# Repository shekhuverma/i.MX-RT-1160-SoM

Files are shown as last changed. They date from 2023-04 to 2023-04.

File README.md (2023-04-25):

You can read the full blog post [here](https://shekharverma.com/posts/imxrt_som/)!

**The SoM Features**
* i.MX RT 1160 MCU (MIMXRT1166DVM6A)
* 128 Mb SD RAM
* 128 Mb QSPI Flash
* 4 Gb eMMC
* 10/100 Mbps RMII Ethernet PHY
* 2 Lane MIPI-DSI
* 2 Lane MIPI-CSI
* 2 X USB 2.0
* 2 X I2C
* UART to USB Convertor
* Multiple GPIOs
* 2 X 48 Pin Board-to-Board Connector

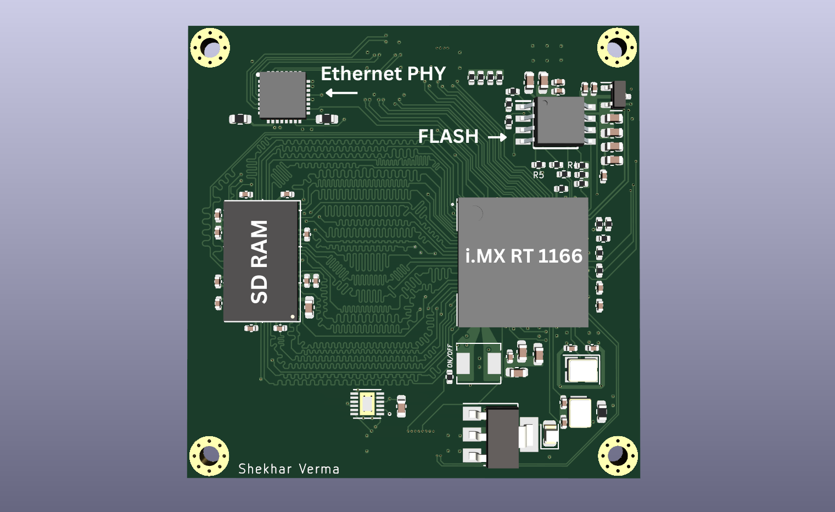
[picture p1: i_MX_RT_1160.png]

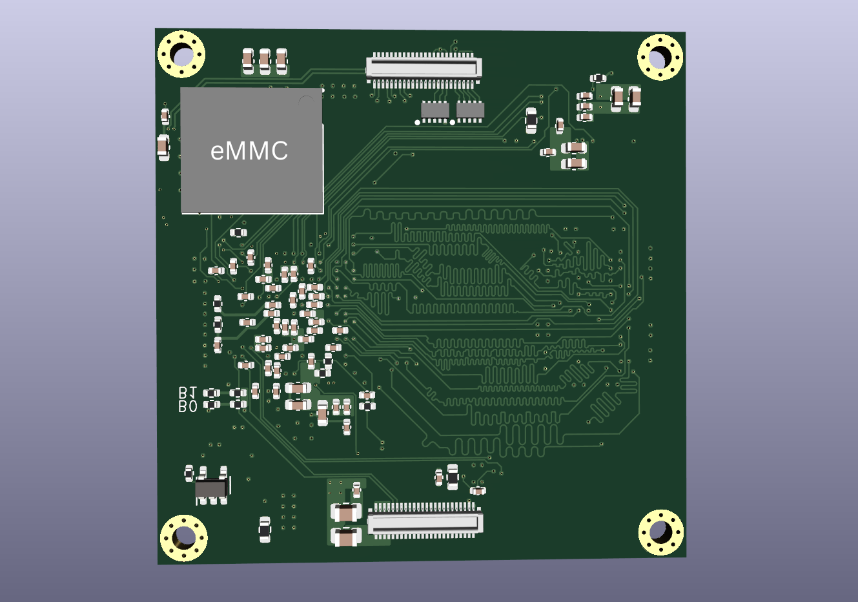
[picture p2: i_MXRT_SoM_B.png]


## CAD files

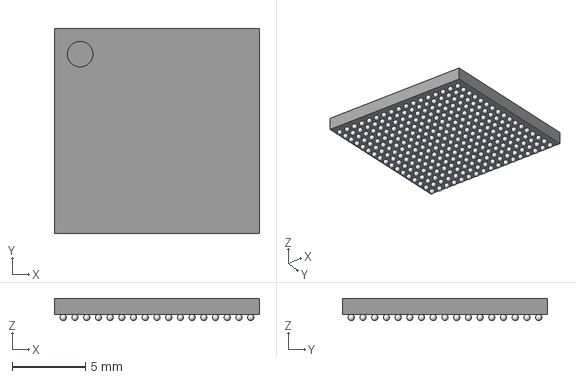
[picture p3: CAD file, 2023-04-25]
Components/MIMXRT1166DVM6A/MIMXRT1166DVM6A.stp
14.0 x 14.0 x 1.52 mm

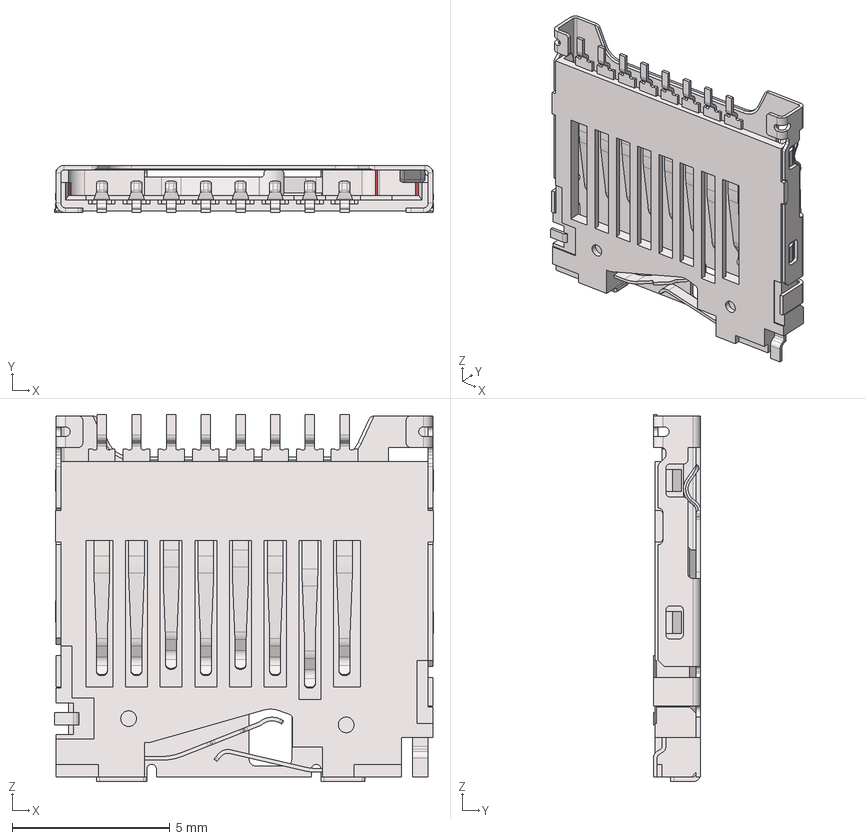
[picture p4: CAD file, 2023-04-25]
Components/1140084168/1140084168.step
12.0 x 1.50 x 11.7 mm

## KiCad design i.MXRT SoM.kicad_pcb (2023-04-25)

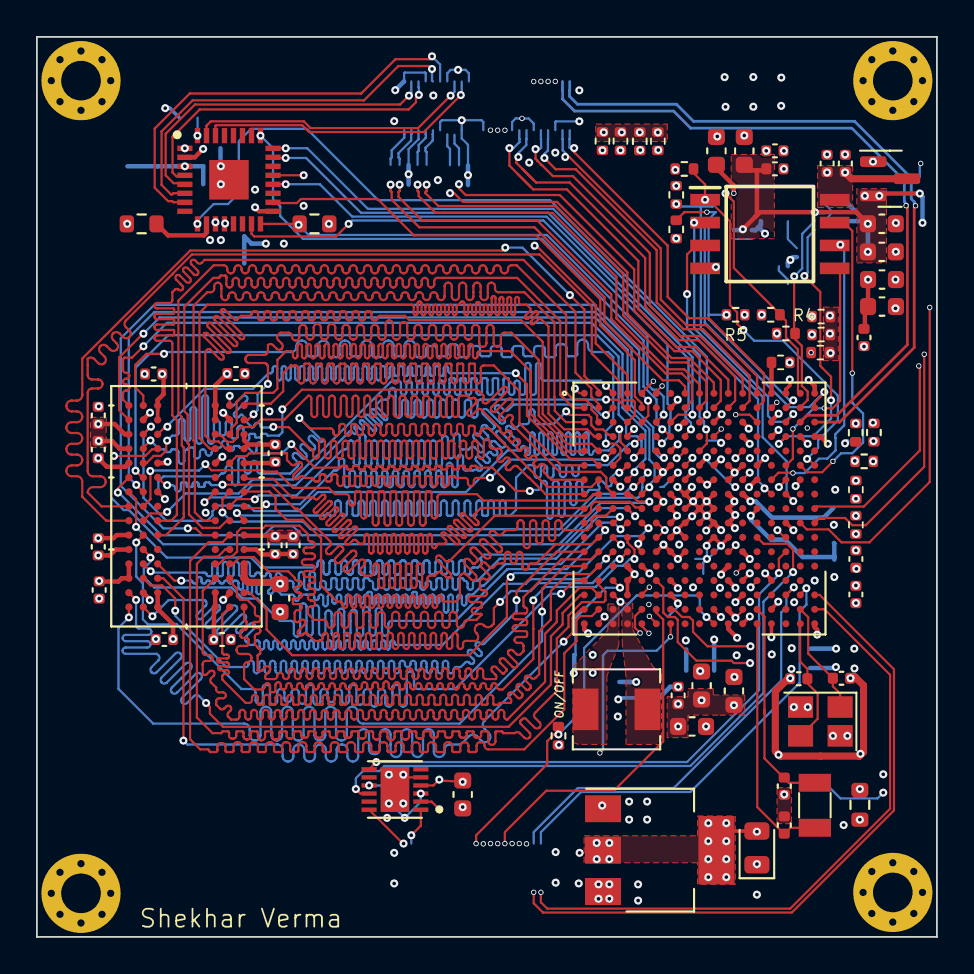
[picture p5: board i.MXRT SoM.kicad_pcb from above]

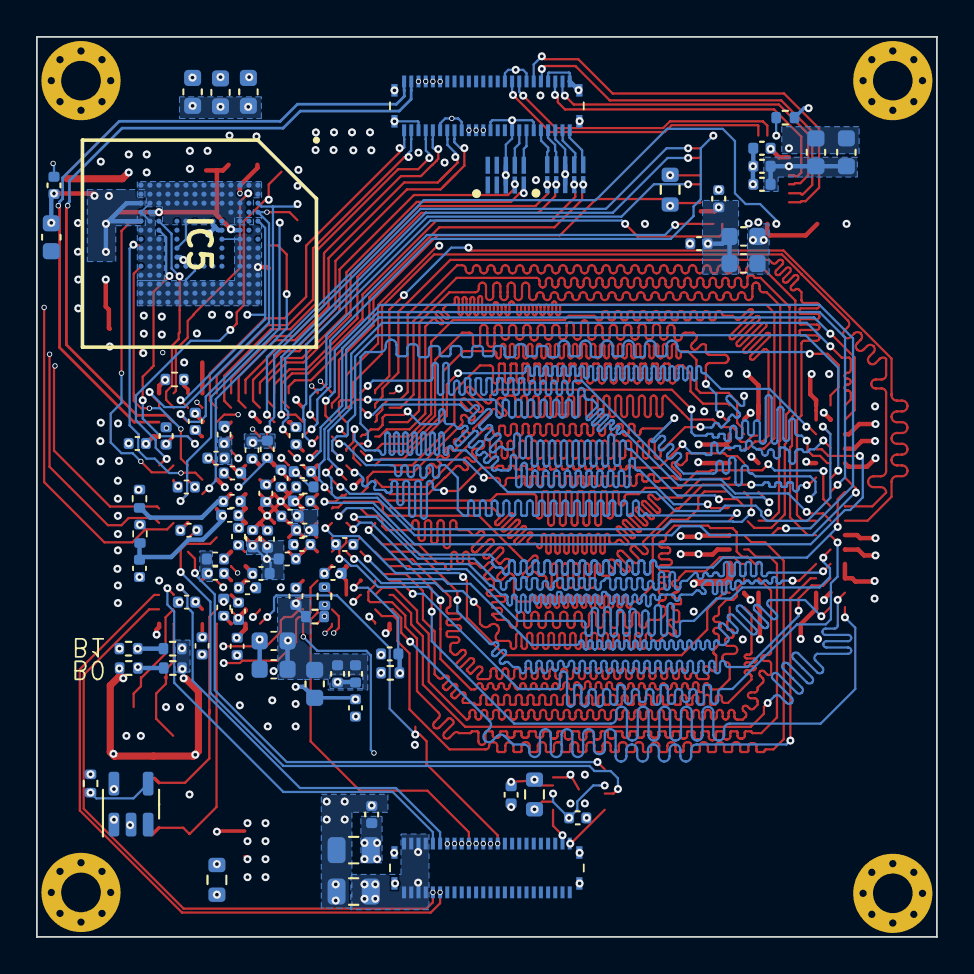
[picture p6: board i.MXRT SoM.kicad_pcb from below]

Board: 6 copper layers, 50.0 x 50.0 mm, 157 parts (85 on the bottom side), 170 nets.

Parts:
C1, C43, C49, C50, C58: 22uF; C_0603_1608Metric
C2, C8, C9, C10, C11, C21, C31, C35, C45, C57: 4.7uF; C_0402_1005Metric
C3, C15, C16, C26, C37, C41, C46, C48, C51, C53, C59, C60, C61, C62, C63, C64, C65, C66, C67, C68, C76, C89, C96: 0.1uF; C_0402_1005Metric
C4, C5, C6, C14, C20, C25, C28, C32, C36, C55: 1uF; C_0402_1005Metric
C7, C17: 0.22uF; C_0402_1005Metric
C12, C13, C18, C19, C22, C23, C24, C27, C29, C30, C33, C34, C40, C44, C69, C92, C99: 2.2uF; C_0402_1005Metric
C38, C39, C87, C88: 4.7pF; C_0402_1005Metric
C42, C47, C78, C82: 10uF; C_0603_1608Metric
C52, C72, C80, C83, C85: 100nF; C_0402_1005Metric
C54, C73, C81, C86, C98: 1uF; C_0603_1608Metric
C56: 2nF; C_0402_1005Metric
C70, C71: 10uF; C_0805_2012Metric
C74, C75: 2.2uF; C_0603_1608Metric
C77, C79: 10nF; C_0402_1005Metric
C84: 4.7uF; C_0603_1608Metric
C90, C91, C93, C94, C95: 0.1uF; C_0603_1608Metric
D1: Green LED; LED_0805_2012Metric
FB1, FB2, FB3, FB4: 120Ohm@100Mhz; R_0402_1005Metric
H1, H2, H3, H4: MountingHole_Pad; MountingHole_2.2mm_M2_Pad_Via
IC1, IC2: ECMF04-4HSM10
IC3: DP83826ERHBR; QFN50P500X500X100-33N-D
IC5: THGBMTG5D1LBAIL; BGA153C50P14X14_1150X1300X80
IC6: W25Q16JVSSIQ; SOIC127P790X216-8N
J1, J2: DF40GB-48DP-0.4V_58_; DF40GB48DP04V58
L1: 4.7uH; AMDLA4020Q-4R7MT
R1: 30K; R_0402_1005Metric
R2, R3, R4, R5, R7, R8, R32: 10K; R_0402_1005Metric
R6, R11: 4.7K; R_0402_1005Metric
R9, R12, R25, R26: DNP; R_0402_1005Metric
R10, R13, R14, R15, R16, R17, R18, R19, R20, R21, R22, R23, R24: 100K; R_0402_1005Metric
R27: 100; R_0603_1608Metric
R28, R41: 10K; R_0603_1608Metric
R29: 6.49K 1%; R_0603_1608Metric
R30, R31: 2.49K 1%; R_0603_1608Metric
R36: 0; R_0402_1005Metric
U1: MIMXRT1166DVM6A
U3: AS4C4M32S-6BIN
U4: LD1117S33TR_SOT223; SOT-223-3_TabPin2
U5: RP300N27AA; SOT-23-5
U6: FT234XD-R; SON45P300X300X80-13N
U7: MCP1700T-1802E/TT; SOT-23
Y1: Crystal_GND24; Crystal_SMD_SeikoEpson_FA238-4Pin_3.2x2.5mm
Y3: 32.768Khz; Crystal_SMD_3215-2Pin_3.2x1.5mm

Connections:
5V: C70.1, J2.21, J2.22, J2.23, J2.24, J2.45, J2.46, J2.47, J2.48, U4.3 (VI)
/MCU_POWER/VDD_SNVS_DIG: C17.1, U1.T14 (VDD_SNVS_DIG)
A0: U1.A3 (GPIO_EMC_B1_09), U3.G8 (A0)
A1: U1.A2 (GPIO_EMC_B1_10), U3.G9 (A1)
A2: U1.C2 (GPIO_EMC_B1_11), U3.F7 (A2)
A3: U1.C5 (GPIO_EMC_B1_12), U3.F3 (A3)
A4: U1.D5 (GPIO_EMC_B1_13), U3.G1 (A4)
A5: U1.B1 (GPIO_EMC_B1_14), U3.G2 (A5)
A6: U1.C1 (GPIO_EMC_B1_15), U3.G3 (A6)
A7: U1.D3 (GPIO_EMC_B1_16), U3.H1 (A7)
A8: U1.B3 (GPIO_EMC_B1_17), U3.H2 (A8)
A9: U1.B4 (GPIO_EMC_B1_18), U3.J3 (A9)
A10: U1.B2 (GPIO_EMC_B1_23), U3.G7 (A10)
A11: U1.C4 (GPIO_EMC_B1_19), U3.H9 (A11)
BA0: U1.G2 (GPIO_EMC_B1_21), U3.J7 (BA0)
BA1: U1.H2 (GPIO_EMC_B1_22), U3.H8 (BA1)
CSI_CK_N: J1.5, U1.A12 (MIPI_CSI_CKN)
CSI_CK_P: J1.4, U1.B12 (MIPI_CSI_CKP)
CSI_D0_N: J1.8, U1.A11 (MIPI_CSI_DN0)
CSI_D0_P: J1.7, U1.B11 (MIPI_CSI_DP0)
CSI_D1_N: J1.2, U1.A13 (MIPI_CSI_DN1)
CSI_D1_P: J1.1, U1.B13 (MIPI_CSI_DP1)
DCDC_1V8: C20.1, C26.1, C33.1, C37.1, C40.1, C42.1, C43.1, C46.1, FB1.2, FB3.2, U1.G16 (ADC_VREFH), U1.K15 (VDDA_ADC_1P8), U1.M6 (DCDC_ANA_SENSE), U1.M7 (DCDC_ANA), U1.M8 (DCDC_ANA), U1.M11 (VDDA_1P8_IN)
DCDC_IN: C4.1, C10.1, C11.1, C12.1, C13.1, C18.1, C21.1, C22.1, C23.1, C24.1, C27.1, C30.1, C31.1, C45.1, C48.1, C50.1, C52.1, C53.1, C54.1, C55.1, C57.1, C58.1, C59.1, C60.1, C61.1, C62.1, C63.1, C64.1, C65.1, C66.1, C67.1, C68.1, C71.1, C72.1, C74.1, C75.1, C76.2, C77.1, C78.1, C79.2, C80.2, C81.2, C82.2, C83.1, C84.1, C86.2, C89.2, C90.2, C91.2, D1.2 (A), FB2.2, FB4.2, IC3.3 (VDDA3V3), IC3.17 (VDDIO), IC5.E6 (VCC_1), IC5.F5 (VCC_2), IC5.J10 (VCC_3), IC5.K9 (VCC_4), IC6.8 (VCC), R1.2, R2.2, R3.2, R4.2, R5.2, R7.2, R8.2, R9.2, R11.2, R26.1, R28.1, R31.1, R32.1, R41.2, U1.D12 (NVCC_DISP1), U1.D14 (NVCC_SD1), U1.E7 (NVCC_DISP2), U1.F6 (NVCC_EMC1), U1.F7 (NVCC_EMC1), U1.G6 (NVCC_EMC1), U1.G13 (NVCC_SD2), U1.H6 (NVCC_EMC2), U1.J6 (NVCC_EMC2), U1.L5 (DCDC_IN_Q), U1.M5 (DCDC_IN), U1.M12 (NVCC_GPIO), U1.N5 (DCDC_IN), U1.P7 (NVCC_LPSR), U1.R12 (VDD_LPSR_IN), U1.U12 (VDD_SNVS_IN), U3.A7 (VDD), U3.B2 (VDDQ), U3.B7 (VDDQ), U3.C9 (VDDQ), U3.D9 (VDDQ), U3.E1 (VDDQ), U3.F9 (VDD), U3.L1 (VDDQ), U3.L7 (VDD), U3.M9 (VDDQ), U3.N9 (VDDQ), U3.P2 (VDDQ), U3.P7 (VDDQ), U3.R7 (VDD), U4.2 (VO), U5.5 (VDD), U6.4 (VCC), U7.3 (VI)
DCDC_LN: L1.1, U1.T4 (DCDC_LN), U1.U4 (DCDC_LN)
DCDC_LP: L1.2, U1.T3 (DCDC_LP), U1.U3 (DCDC_LP)
DQ0: U1.F3 (GPIO_EMC_B1_00), U3.R8 (DQ0)
DQ1: U1.F2 (GPIO_EMC_B1_01), U3.N7 (DQ1)
DQ2: U1.G4 (GPIO_EMC_B1_02), U3.R9 (DQ2)
DQ3: U1.E4 (GPIO_EMC_B1_03), U3.N8 (DQ3)
DQ4: U1.H5 (GPIO_EMC_B1_04), U3.P9 (DQ4)
DQ5: U1.F4 (GPIO_EMC_B1_05), U3.M8 (DQ5)
DQ6: U1.H4 (GPIO_EMC_B1_06), U3.M7 (DQ6)
DQ7: U1.H3 (GPIO_EMC_B1_07), U3.L8 (DQ7)
DQ8: U1.E3 (GPIO_EMC_B1_30), U3.L2 (DQ8)
DQ9: U1.D2 (GPIO_EMC_B1_31), U3.M3 (DQ9)
DQ10: U1.D1 (GPIO_EMC_B1_32), U3.M2 (DQ10)
DQ11: U1.E2 (GPIO_EMC_B1_33), U3.P1 (DQ11)
DQ12: U1.E1 (GPIO_EMC_B1_34), U3.N2 (DQ12)
DQ13: U1.F1 (GPIO_EMC_B1_35), U3.R1 (DQ13)
DQ14: U1.G1 (GPIO_EMC_B1_36), U3.N3 (DQ14)
DQ15: U1.H1 (GPIO_EMC_B1_37), U3.R2 (DQ15)
DQ16: U1.K2 (GPIO_EMC_B2_00), U3.E8 (DQ16)
DQ17: U1.K4 (GPIO_EMC_B2_01), U3.D7 (DQ17)
DQ18: U1.K3 (GPIO_EMC_B2_02), U3.D8 (DQ18)
DQ19: U1.R1 (GPIO_EMC_B2_03), U3.B9 (DQ19)
DQ20: U1.M1 (GPIO_EMC_B2_04), U3.C8 (DQ20)
DQ21: U1.N1 (GPIO_EMC_B2_05), U3.A9 (DQ21)
DQ22: U1.T1 (GPIO_EMC_B2_06), U3.C7 (DQ22)
DQ23: U1.M3 (GPIO_EMC_B2_07), U3.A8 (DQ23)
DQ24: U1.N2 (GPIO_EMC_B2_09), U3.A2 (DQ24)
DQ25: U1.R2 (GPIO_EMC_B2_10), U3.C3 (DQ25)
DQ26: U1.L4 (GPIO_EMC_B2_11), U3.A1 (DQ26)
DQ27: U1.M2 (GPIO_EMC_B2_12), U3.C2 (DQ27)
DQ28: U1.K5 (GPIO_EMC_B2_13), U3.B1 (DQ28)
DQ29: U1.M4 (GPIO_EMC_B2_14), U3.D2 (DQ29)
DQ30: U1.L2 (GPIO_EMC_B2_15), U3.D3 (DQ30)
DQ31: U1.P2 (GPIO_EMC_B2_16), U3.E2 (DQ31)
DQM0: U1.F5 (GPIO_EMC_B1_08), U3.K9 (DQM0)
DQM1: U1.J1 (GPIO_EMC_B1_38), U3.K1 (DQM1)
DQM2: U1.P1 (GPIO_EMC_B2_08), U3.F8 (DQM2)
DQM3: U1.T2 (GPIO_EMC_B2_17), U3.F2 (DQM3)
DSI_CK_MCU_N: IC1.2 (D1-_1), U1.A9 (MIPI_DSI_CKN)
DSI_CK_MCU_P: IC1.1 (D1+_1), U1.B9 (MIPI_DSI_CKP)
DSI_CK_N: IC1.9 (D1-_2), J1.21
DSI_CK_P: IC1.10 (D1+_2), J1.20
DSI_D0_MCU_N: IC1.5 (D2-_1), U1.A8 (MIPI_DSI_DN0)
DSI_D0_MCU_P: IC1.4 (D2+_1), U1.B8 (MIPI_DSI_DP0)
DSI_D0_N: IC1.6 (D2-_2), J1.24
DSI_D0_P: IC1.7 (D2+_2), J1.23
DSI_D1_MCU_N: IC2.5 (D2-_1), U1.A10 (MIPI_DSI_DN1)
DSI_D1_MCU_P: IC2.4 (D2+_1), U1.B10 (MIPI_DSI_DP1)
DSI_D1_N: IC2.6 (D2-_2), J1.18
DSI_D1_P: IC2.7 (D2+_2), J1.17
EMMC_CLK: IC5.M6 (CLK), U1.D15 (GPIO_SD_B1_01)
EMMC_CMD: IC5.M5 (CMD), R2.1, U1.B16 (GPIO_SD_B1_00)
EMMC_D0: IC5.A3 (DAT0), R8.1, U1.C15 (GPIO_SD_B1_02)
EMMC_D1: IC5.A4 (DAT1), R7.1, U1.B17 (GPIO_SD_B1_03)
EMMC_D2: IC5.A5 (DAT2), R5.1, U1.B15 (GPIO_SD_B1_04)
EMMC_D3: IC5.B2 (DAT3), R4.1, U1.A16 (GPIO_SD_B1_05)
ENET_CRS_DV: IC3.18 (RX_DV/CRS_DV/STRAP10), U1.B5 (GPIO_DISP_B2_08)
ENET_INT: IC3.21 (PWRDN/INT), R31.2, U1.P17 (GPIO_AD_12)
ENET_LED0: IC3.30 (LED0/STRAP2), J1.40
ENET_LED1: IC3.31 (CLKOUT/LED1/STRAP1), J1.41
ENET_MDC: IC3.12 (MDC), U1.U2 (GPIO_EMC_B2_19)
ENET_MDIO: IC3.11 (MDIO), U1.R3 (GPIO_EMC_B2_20)
ENET_RST: IC3.32 (RST_N), R36.2
ENET_RX_D0: IC3.16 (STRAP0/RX_D0), R30.2, U1.C6 (GPIO_DISP_B2_06)
ENET_RX_D1: IC3.15 (STRAP9/RX_D1), U1.D6 (GPIO_DISP_B2_07)
ENET_RX_ER: IC3.20 (RX_ER/STRAP6), U1.D8 (GPIO_DISP_B2_09)
ENET_TX_CLK: IC3.9 (XI/50MHZIN), R20.2, U1.C9 (GPIO_DISP_B2_05)
ENET_TX_D0: IC3.24 (TX_D0), R23.2, U1.E9 (GPIO_DISP_B2_02)
ENET_TX_D1: IC3.25 (TX_D1), R24.2, U1.D7 (GPIO_DISP_B2_03)
ENET_TX_EN: IC3.23 (TX_EN), R19.2, U1.C7 (GPIO_DISP_B2_04)
GND: C1.2, C2.2, C3.2, C4.2, C5.2, C6.2, C7.2, C8.2, C9.2, C10.2, C11.2, C12.2, C13.2, C14.2, C15.2, C16.2, C17.2, C18.2, C19.2, C20.2, C21.2, C22.2, C23.2, C24.2, C25.2, C26.2, C27.2, C28.2, C29.2, C30.2, C31.2, C32.2, C33.2, C34.1, C35.1, C36.2, C37.2, C38.1, C39.2, C40.2, C41.2, C42.2, C43.2, C44.2, C45.2, C46.2, C47.2, C48.2, C49.2, C50.2, C51.2, C52.2, C53.2, C54.2, C55.2, C56.1, C57.2, C58.2, C59.2, C60.2, C61.2, C62.2, C63.2, C64.2, C65.2, C66.2, C67.2, C68.2, C69.2, C70.2, C71.2, C72.2, C73.2, C74.2, C75.2, C76.1, C77.2, C78.2, C79.1, C80.1, C81.1, C82.1, C83.2, C84.2, C85.2, C86.1, C87.1, C88.2, C89.1, C90.1, C91.1, C92.2, C93.1, C94.1, C95.1, C96.1, C98.1, C99.2, H1.1, H2.1, H3.1, H4.1, IC1.3 (GND_1), IC1.8 (GND_2), IC2.3 (GND_1), IC2.8 (GND_2), IC3.1 (MODESELECT), IC3.33 (EP), IC5.A1 (NC), IC5.A2 (NC), IC5.A6 (VSS_1), IC5.A8 (NC), IC5.A9 (NC), IC5.A10 (NC), IC5.A11 (NC), IC5.A12 (NC), IC5.A13 (NC), IC5.A14 (NC), IC5.B1 (NC), IC5.B7 (NC), IC5.B8 (NC), IC5.B9 (NC), IC5.B10 (NC), IC5.B11 (NC), IC5.B12 (NC), IC5.B13 (NC), IC5.B14 (NC), IC5.C1 (NC), IC5.C3 (NC), IC5.C4 (VSSQ_1), IC5.C5 (NC), IC5.C7 (NC), IC5.C8 (NC), IC5.C9 (NC), IC5.C10 (NC), IC5.C11 (NC), IC5.C12 (NC), IC5.C13 (NC), IC5.C14 (NC), IC5.D1 (NC), IC5.D2 (NC), IC5.D3 (NC), IC5.D4 (NC), IC5.D12 (NC), IC5.D13 (NC), IC5.D14 (NC), IC5.E1 (NC), IC5.E2 (NC), IC5.E3 (NC), IC5.E7 (VSS_2), IC5.E12 (NC), IC5.E13 (NC), IC5.E14 (NC), IC5.F1 (NC), IC5.F2 (NC), IC5.F3 (NC), IC5.F12 (NC), IC5.F13 (NC), IC5.F14 (NC), IC5.G1 (NC), IC5.G2 (NC), IC5.G3 (NC), IC5.G5 (VSS_3), IC5.G12 (NC), IC5.G13 (NC), IC5.G14 (NC), IC5.H1 (NC), IC5.H2 (NC), IC5.H3 (NC), IC5.H10 (VSS_4), IC5.H12 (NC), IC5.H13 (NC), IC5.H14 (NC), IC5.J1 (NC), IC5.J2 (NC), IC5.J3 (NC), IC5.J5 (VSS_5), IC5.J12 (NC), IC5.J13 (NC), IC5.J14 (NC), IC5.K1 (NC), IC5.K2 (NC), IC5.K3 (NC), IC5.K8 (VSS_6), IC5.K12 (NC), IC5.K13 (NC), IC5.K14 (NC), IC5.L1 (NC), IC5.L2 (NC), IC5.L3 (NC), IC5.L12 (NC), IC5.L13 (NC), IC5.L14 (NC), IC5.M1 (NC), IC5.M2 (NC), IC5.M3 (NC), IC5.M7 (NC), IC5.M8 (NC), IC5.M9 (NC), IC5.M10 (NC), IC5.M11 (NC), IC5.M12 (NC), IC5.M13 (NC), IC5.M14 (NC), IC5.N1 (NC), IC5.N2 (VSSQ_2), IC5.N3 (NC), IC5.N5 (VSSQ_3), IC5.N6 (NC), IC5.N7 (NC), IC5.N8 (NC), IC5.N9 (NC), IC5.N10 (NC), IC5.N11 (NC), IC5.N12 (NC), IC5.N13 (NC), IC5.N14 (NC), IC5.P1 (NC), IC5.P2 (NC), IC5.P4 (VSSQ_4), IC5.P6 (VSSQ_5), IC5.P8 (NC), IC5.P9 (NC), IC5.P11 (NC), IC5.P12 (NC), IC5.P13 (NC), IC5.P14 (NC), IC6.4 (GND), J1.3, J1.6, J1.9, J1.13, J1.16, J1.19, J1.22, J1.30, J1.39, J1.42, J1.45, J1.48, J1.MP1, J1.MP2, J1.MP3, J1.MP4, J2.12, J2.18, J2.MP1, J2.MP2, J2.MP3, J2.MP4, R6.1, R10.1, R12.1, R13.1, R14.1, R15.1, R16.1, R17.1, R18.1, R19.1, R20.1, R21.1, R22.1, R23.1, R24.1, R27.2, R29.1, R30.1, U1.A1 (VSS), U1.A17 (VSS), U1.B7 (VSS), U1.C8 (VSS), U1.C10 (VSS), U1.C12 (VSS), U1.C14 (VSS), U1.D4 (VSS), U1.F11 (VSS), U1.F12 (VSS), U1.F13 (VSS), U1.G3 (VSS), U1.G7 (VSS), U1.G8 (VSS), U1.G9 (VSS), U1.G10 (VSS), U1.G11 (VSS), U1.G15 (VSS), U1.H7 (VSS), U1.H11 (VSS), U1.J7 (VSS), U1.J11 (VSS), U1.K6 (DCDC_GND), U1.K7 (DCDC_GND), U1.K11 (VSS), U1.L3 (VSS), U1.L6 (DCDC_GND), U1.L10 (VSS), U1.L11 (VSS), U1.L15 (VSS), U1.N4 (DCDC_MODE), U1.P4 (VSS), U1.P14 (VSS), U1.R4 (VSS), U1.R7 (VSS), U1.T11 (TEST_MODE), U1.T12 (VSS), U1.U1 (VSS), U1.U17 (VSS), U3.A3 (VSS), U3.B3 (VSSQ), U3.B8 (VSSQ), U3.C1 (VSSQ), U3.D1 (VSSQ), U3.E9 (VSSQ), U3.F1 (VSS), U3.L3 (VSS), U3.L9 (VSSQ), U3.M1 (VSSQ), U3.N1 (VSSQ), U3.P3 (VSSQ), U3.P8 (VSSQ), U3.R3 (VSS), U4.1 (GND), U5.2 (GND), U6.5 (GND), U6.13 (GND), U7.1 (GND), Y1.2, Y1.4
GPIO1: J1.12, U1.A4 (GPIO_DISP_B2_15)
GPIO2: J1.10, U1.A6 (GPIO_DISP_B2_11)
GPIO3: J1.11, U1.A5 (GPIO_DISP_B2_13)
GPIO4: J2.17, U1.P13 (GPIO_AD_05)
GPIO5: J2.44, U1.T17 (GPIO_AD_07)
GPIO6: J2.43, U1.R17 (GPIO_AD_10)
GPIO_LPSR_02: R9.1, R10.2, U1.P6 (GPIO_LPSR_02)
GPIO_LPSR_03: R11.1, R12.2, U1.T7 (GPIO_LPSR_03)
I2C2_SCL: J2.19, U1.R15 (GPIO_AD_08)
I2C2_SDA: J2.20, U1.R16 (GPIO_AD_09)
JTAG_TCK/SWCLK: J2.15, U1.T6 (GPIO_LPSR_14)
JTAG_TDI: J2.14, U1.U5 (GPIO_LPSR_12)
JTAG_TDO: J2.13, U1.T5 (GPIO_LPSR_11)
JTAG_TMS/SWDIO: J2.16, U1.U7 (GPIO_LPSR_15)
NRST: R28.2, U5.1 (~MR)
unnamed: D1.1 (K), R27.1
unnamed: C56.2, IC3.2 (CEXT)
unnamed: IC3.10 (RBIAS), R29.2
unnamed: C73.1, IC5.C2 (VDDI)
unnamed: C7.1, R1.1, U1.P3 (DCDC_PSWITCH)
unnamed: C14.1, C16.1, FB4.1, U1.J13 (VDDA_ADC_3P3)
unnamed: C35.2, U1.P12 (VDD_LPSR_ANA)
unnamed: C34.2, U1.P11 (VDD_LPSR_DIG)
unnamed: C25.1, FB1.1, U1.F9 (VDD_MIPI_1P8)
unnamed: C36.1, FB3.1, U1.H12 (VDD_USB_1P8)
unnamed: C32.1, FB2.1, U1.G12 (VDD_USB_3P3)
unnamed: R17.2, U1.D10 (GPIO_DISP_B1_06)
unnamed: R18.2, U1.E12 (GPIO_DISP_B1_07)
unnamed: R13.2, U1.A15 (GPIO_DISP_B1_08)
unnamed: R14.2, U1.C13 (GPIO_DISP_B1_09)
unnamed: R15.2, U1.B14 (GPIO_DISP_B1_10)
unnamed: R16.2, U1.A14 (GPIO_DISP_B1_11)
unnamed: R21.2, U1.E8 (GPIO_DISP_B2_00)
unnamed: R22.2, U1.F8 (GPIO_DISP_B2_01)
unnamed: R32.2, U1.R5 (GPIO_LPSR_10)
unnamed: R6.2, U1.U6 (GPIO_LPSR_13)
unnamed: C39.1, U1.U16 (XTALI), Y1.3
unnamed: C38.2, U1.T16 (XTALO), Y1.1
unnamed: C85.1, U6.3 (3V3OUT), U6.9 (VCCIO)
unnamed: R41.1, U6.2 (~RESET#)
ON/OFF: J2.11, R26.2, U1.U10 (ONOFF)
POR_B: R25.2, R36.1, U1.T10 (POR_B), U5.4 (out)
QSPI_CLK: IC6.6 (CLK), U1.G14 (GPIO_SD_B2_07)
QSPI_CS: IC6.1 (/CS), R3.1, U1.F17 (GPIO_SD_B2_06)
QSPI_IO_0: IC6.5 (DI_(IO0)), U1.F15 (GPIO_SD_B2_08)
QSPI_IO_1: IC6.2 (DO_(IO1)), U1.H15 (GPIO_SD_B2_09)
QSPI_IO_2: IC6.3 (IO2), U1.H14 (GPIO_SD_B2_10)
QSPI_IO_3: IC6.7 (IO3), U1.F16 (GPIO_SD_B2_11)
RD_N: IC3.4 (RD_M), J1.46
RD_P: IC3.5 (RD_P), J1.47
RTC_XTALI: C88.1, U1.T13 (RTC_XTALI), Y3.2
RTC_XTALO: C87.2, U1.U13 (RTC_XTALO), Y3.1
SDCAS: U1.J5 (GPIO_EMC_B1_24), U3.K7 (*CAS)
SDCKE: U1.G5 (GPIO_EMC_B1_27), U3.J2 (CKE)
SDCLK: U1.J3 (GPIO_EMC_B1_26), U3.J1 (CLK)
SDCS: U1.E6 (GPIO_EMC_B1_29), U3.J8 (*CS)
SDRAS: U1.J4 (GPIO_EMC_B1_25), U3.J9 (*RAS)
SDWE: U1.E5 (GPIO_EMC_B1_28), U3.K8 (*WE)
TD_N: IC3.6 (TD_M), J1.44
TD_P: IC3.7 (TD_P), J1.43
UART_RX: U1.M15 (GPIO_AD_25), U6.7 (TXD)
UART_TX: U1.L13 (GPIO_AD_24), U6.10 (RXD)
UART_USB_N: J2.2, U6.1 (USBDM)
UART_USB_P: J2.1, U6.12 (USBDP)
USB2_DN: J1.26, U1.C16 (USB2_DN)
USB2_DP: J1.25, U1.C17 (USB2_DP)
USB_OTG1: C99.1, U1.D16 (USB2_VBUS)
USB_OTG2: C69.1, U1.D17 (USB1_VBUS)
USB_OTG2_ID: J1.29, U1.K16 (GPIO_AD_32)
USB_OTG2_OC: J1.28, U1.K17 (GPIO_AD_30)
USB_OTG2_PWR: J1.27, U1.J17 (GPIO_AD_31)
VDD_1P0: C28.1, C29.1, U1.F10 (VDD_MIPI_1P0), U1.N11 (VDDA_1P0)
VDD_1V8: C92.1, C93.2, C94.2, C95.2, C96.2, C98.2, IC5.C6 (VCCQ_1), IC5.M4 (VCCQ_2), IC5.N4 (VCCQ_3), IC5.P3 (VCCQ_4), IC5.P5 (VCCQ_5), U7.2 (VO)
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

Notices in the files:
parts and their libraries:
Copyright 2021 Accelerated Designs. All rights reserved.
